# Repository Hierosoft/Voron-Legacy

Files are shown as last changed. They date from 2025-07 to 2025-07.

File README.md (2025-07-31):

# VORON Legacy

Image of Voron Legacy

The official release of the Voron Legacy 3d printer. You can find the BOM and any other relevant information at the [Voron Design]( http://vorondesign.com/voron_legacy) website.

Voron Logo

## Sourcing Guide
- See "VORON 1.6.2" at [sourcing guides](https://vorondesign.com/sourcing_guide?model=VL) page (1.6.2 is same as Legacy according to nemgrea)

## Assembly
- Voron Legacy [Brief assembly Guide](https://forum.vorondesign.com/threads/brief-assembly-guide.176/) by Sanity Agathion, a Voron forum admininstrator.
- Unofficial assembly video series: [Voron Legacy](https://www.youtube.com/playlist?list=PLm2OH_myqt7a_PT0lViufZZBrC22PzAQH) by [Fugatech 3D Printing](https://www.youtube.com/@Fugatech3DPrinting) on YouTube
  - Uses drop-in not slide-in T-nuts, so if using slide-in ones, take care to insert them before locking them out via assembly. See unofficial assembly manual below for image and description of where to insert them.
- [Voron Legacy Unofficial Manual by Poikilos](https://docs.google.com/document/d/1mR3VX70ok1uY0DY2WcfInHhRfALJT7SdbVQVug27Xh0/edit?usp=sharing)
  (WIP)

### Known issues
(Differences mentioned are from actual measurements of motors, making belts centered on gearheads' teeth, etc. Belts are in blend file in Poikilos' Voron Legacy folder on Google Drive, along with these fixes)
- (CAD folder) Make motor shaft of A & B motors 0.152 mm longer so they are 24mm from the screw surface like motors in the 1.6.2 BOM
- Move A (right) gearhead (20T pulley) down by 2.35 so it is 3.45 less than end of motor shaft
- Move B (left) gearhead (20T pulley) up by 0.10217 so it sticks out 1.25mm more than end of motor shaft
- Add (1) M3X40 socket head screw to each side of rear of X Carriage (2 total)
  - Add (2) threaded inserts for them.
  - 1.25mm of the threads are underutilized, so make socket head holes that much deeper.
- Inductive Probe object is unnamed (Fixed in FreeCAD file).

## Contributors
- [deleted user] via Discord
  - "jig for aligning the Y axis rods with the frame" [2022-08-09](https://discord.com/channels/460117602945990666/791364306276450337/1006420060069441627)
    - y_axis_rod_alignment_jig_x4.stl (originally named legacy_tool.stl)
      - (4) are required as cited on [Brief assembly guide](https://forum.vorondesign.com/threads/brief-assembly-guide.176/)
- Ibbanez VL.029 via Discord
  - "X carriage for Stealthburner with CW2 for VL" [2022-08-24](https://discord.com/channels/460117602945990666/791364306276450337/1012131175113949204) as cited on [Brief assembly guide](https://forum.vorondesign.com/threads/brief-assembly-guide.176/)
    - X-VL_left.stl
    - X-VL_right.stl
- Poikilos
  - Alternate leadscrew block for anti-backlash POM nut (2 shank holes, spaced further apart).
    - Fits ["Ender 3 V2 Z axis T8 POM Anti Backlash Spring Loaded Nut Elimination Gap Compatible with Voron 2.4 Ender3 pro 3D Printer 8mm Acme Threaded Rod"](https://www.amazon.com/dp/B088FPNVVF?ref_=ppx_hzsearch_conn_dt_b_fed_asin_title_1) from POLISI3D Store on Amazon.
      - Be aware, these are consumable (will eventually tear apart and lose the threads)! Regular brass ones are recommended in the sourcing guide.
  - Alternate 206mm bed screw spacing parts (for reusing bed from A8 clone such as A3S)
    - 206mm on y: STLs/Tools/alternate_bed_screw_y_spacing_206mm/z_component_alignment_jig-206mm_bed_screw_spacing_A3S.stl
    - 206mm on x: STLs/Z Axis/Bed Carriages/alternate_bed_screw_x_spacing_206mm/
  - Blend file with the above, blind joints, and taller to use prefabricated Voron 2.4 frame:
    [Poikilos' Voron Legacy Folder](https://drive.google.com/drive/folders/1cWyBRrxuDkORSMTYZdLJZKc8Kg_imgok?usp=sharing) on Google Drive (too large for git except with LFS).
    - [Generated BOM](https://drive.google.com/file/d/1eSlRInvPNuWncBucrcRtuzRmA0uxTkT_/view?usp=sharing), reusing a prefabricated Voron 2.4 frame size
      - No 320 motors exist though, so use a regular stepper motor, flexible coupling (See unofficial sourcing guide below), and ~300mm lead screws such from A8 clone such as A3S.
    - Unofficial sourcing guide by Poikilos: [https://docs.google.com/spreadsheets/d/1isZgUZrGUJIj4jxUcvnwxng9hJ9_i8DxyWfmX4hRLIU/edit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](Building VORON Legacy but with V2.4 Frame and salvaged A8 clone)
      - based on "VORON 1.6.2" at [sourcing guides](https://vorondesign.com/sourcing_guide?model=VL) (1.6.2 is same as Legacy according to nemgrea)

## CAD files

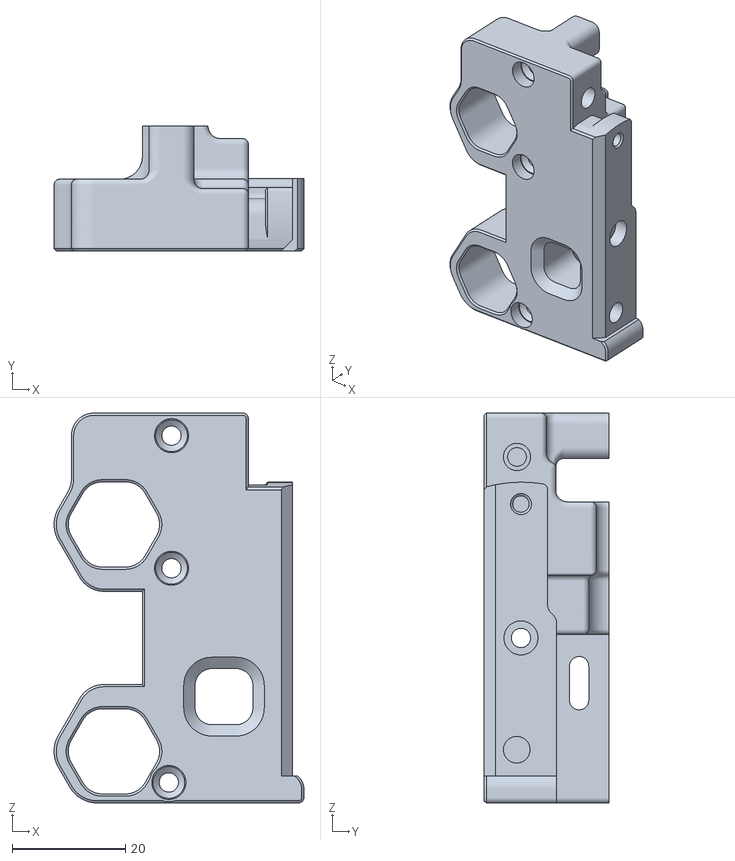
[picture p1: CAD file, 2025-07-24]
STLs/Gantry/X Carriage/Printheads/Stealthburner with CW2/X-VL_left.stl
44.1 x 22.0 x 68.8

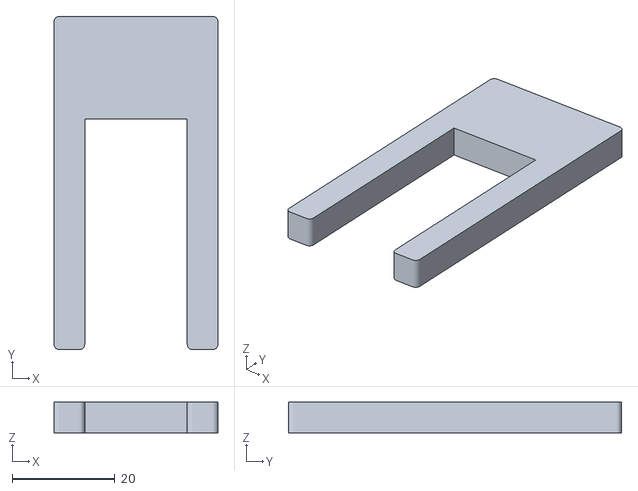
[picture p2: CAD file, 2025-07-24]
STLs/Tools/y_axis_rod_alignment_jig_x4.stl
32.0 x 65.0 x 6.00

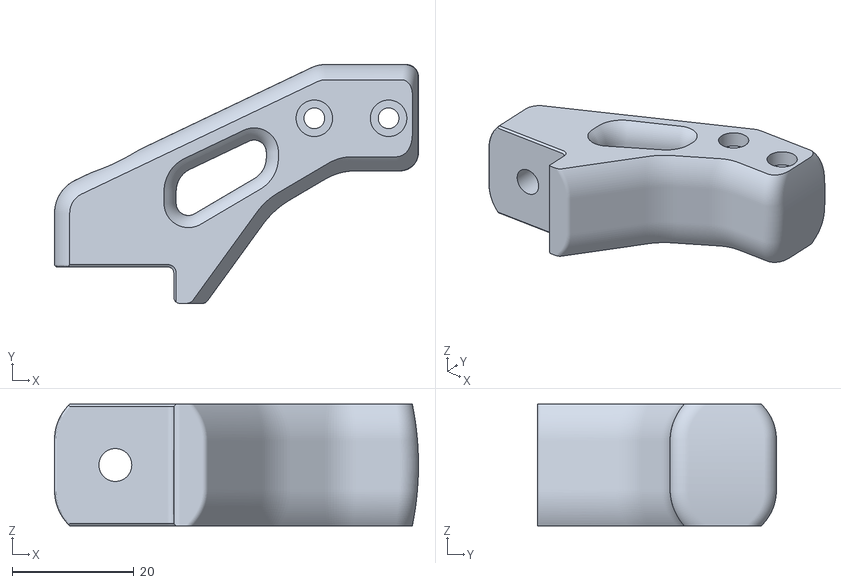
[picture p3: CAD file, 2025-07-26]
STLs/Z Axis/z_shaft_support_lower_a_x2.stl
59.8 x 39.3 x 20.0

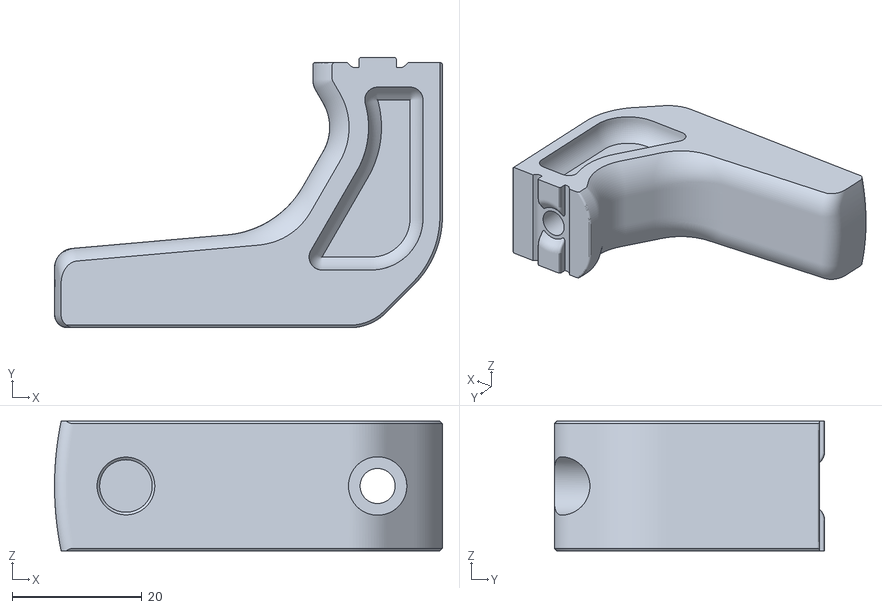
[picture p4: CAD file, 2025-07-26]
STLs/Z Axis/z_shaft_support_upper_x4.stl
59.8 x 41.7 x 20.0

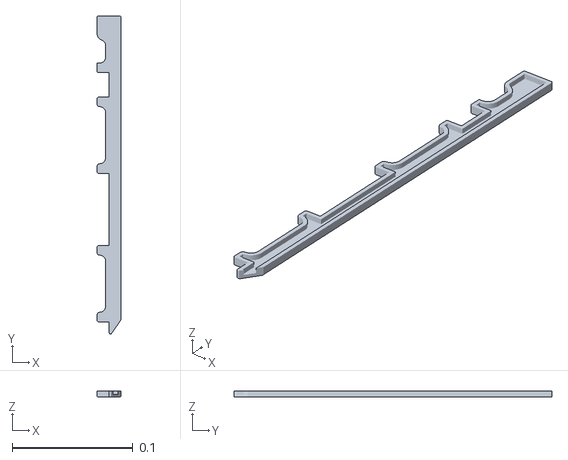
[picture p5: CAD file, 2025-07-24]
STLs/Tools/alternate_bed_screw_y_spacing_206mm/z_component_alignment_jig-206mm_bed_screw_spacing_A3S.stl
0.0196 x 0.263 x 0.005

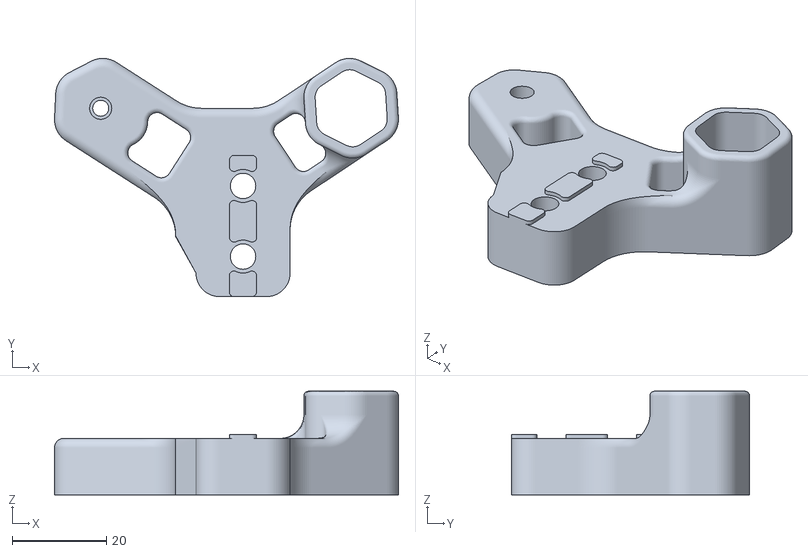
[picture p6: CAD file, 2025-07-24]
STLs/Z Axis/Bed Carriages/alternate_bed_screw_x_spacing_206mm/bed_carriage_upper_b_x2-206mm_bed_screw_y_spacing.stl
73.1 x 50.6 x 22.0

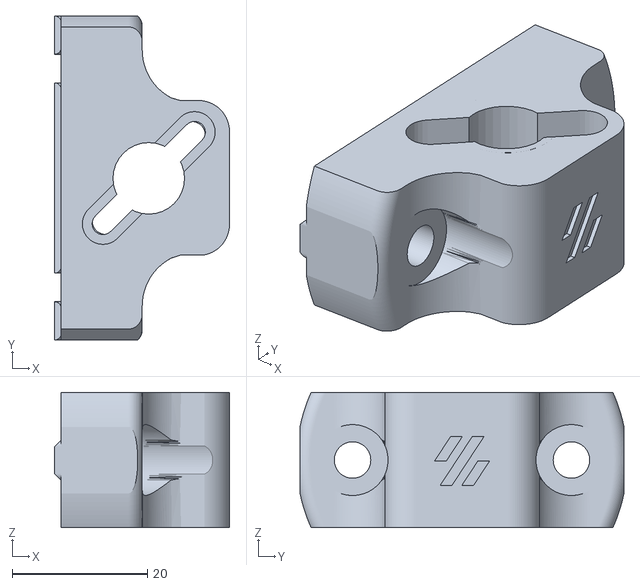
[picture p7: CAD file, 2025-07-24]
STLs/Z Axis/Bed Carriages/for-2-screw-POM_nut/z_leadscrew_block_x2mirror+.5mmx2_clearance-for-2screw-POM-nut.stl
25.9 x 48.0 x 20.0

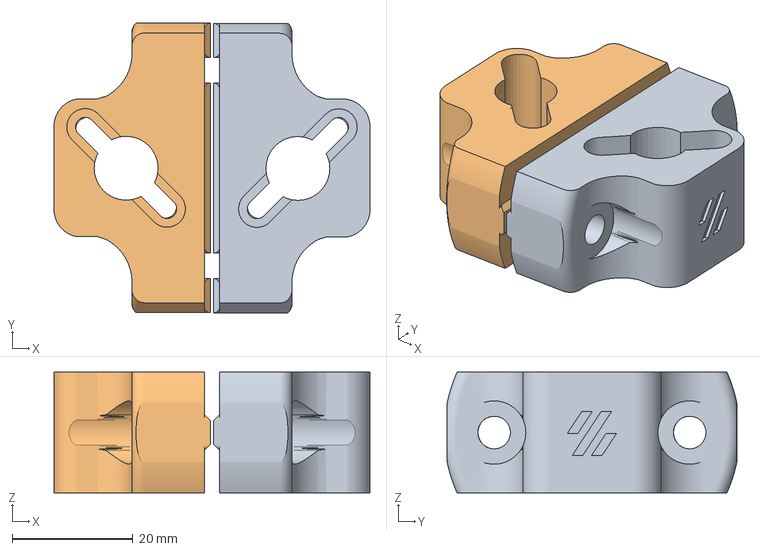
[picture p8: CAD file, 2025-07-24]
STLs/Z Axis/Bed Carriages/for-2-screw-POM_nut/z_leadscrew_block+.5mmx2_clearance-for-2screw-POM-nut-x2-mirrorred.3mf
52.4 x 48.0 x 20.0 mm
z_leadscrew_block_x2+.5mmx2_clearance.stl x 2

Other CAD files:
STLs/Gantry/X Carriage/Printheads/Stealthburner with CW2/X-VL-right.stl
STLs/Z Axis/z_shaft_support_lower_b_x2.stl
STLs/Z Axis/Bed Carriages/alternate_bed_screw_x_spacing_206mm/bed_carriage_upper_a_x2-206mm_bed_screw_y_spacing.stl

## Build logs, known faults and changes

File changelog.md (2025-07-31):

# Changelog

All notable changes to this project will be documented in this file.

The format is based on [Keep a Changelog](https://keepachangelog.com/en/1.1.0/).

## 2025-07-27
### Fixed
- Named unnamed inductive_probe.

## 2025-07-27
(only to blend file in Poikilos' Voron Legacy Folder on Google Drive)
### Added
- Belts (blend file)
### Fixed
- Edit end of A & B motor shafts so they are 24mm from the screw surface like motors in the 1.6.2 BOM.
- Move A (right) gearhead (T20 pulley) down by 2.35 (blend file) so it is out 3.45 less than end of motor shaft
- Move B (left) gearhead (T20 pulley) up by 0.10217 (blend file) so it sticks out 1.25mm more than end of motor shaft
- Move entire scene by -76.8922,-135.07,360.175 mm so top surfaces of bottom bars is at 0 on z axis and outer edge is at 0,0 on x-y plane.
  - Then rotate 180 on world origin so that x and y move in the same direction as they would in firmware and slicer software.

## 2025-07-26
(Poikilos)
### Fixed
- Named more parts in FreeCAD file (and Poikilos' blend file in Google Drive link):
  `front_idler_*`, `bed_carriage_*`, `z_leadscrew_block_x2` `z_shaft_support_upper_*`, `*_drive_unit_*`, `z_shaft_support_lower_*_x2`, `z_motor_mount_*_x2*`, `bowden_adapter_*`, `[a]_bowden_cable_cover`, `blower_housing_rear`, `[a]_blower_housing_front`, `printhead_*_e3dv6`, `probe_retainer_bracket`, `[a]_belt_clip_x2`, `enclosure_cover`, `psu_stabilizer` (was misspelled "Stabalizer"), `xy_joint_*`, `y_bearing_retainer_front_x2`,
  - Helps find the STL you need. Example: identifying parts in (unofficial) documentation visually rather than using a file search.
- Suffix assemblies for parts above with **"_ASSEMBLED"** to avoid confusion on export where parts are fused into one mesh but must be printed separately (impossible to print if fused, but at least user is clued into that fact and knows to not export that. This is fixed in Poikilos' blend file.).
- Parts with ".R" or rear/front in name do not have to be exported more than once (filename is part before dot).

## 2025-07-26
(Poikilos)
### Fixed
- Rename misspelled files: (3) Z axis `*support*` files formerly `*suport*`.

## 2025-07-24
(Poikilos)
### Added
- y axis rod alignment tool [by deleted user on Discord]
- "X carriage for Stealthburner with CW2 for VL" by Ibbanez VL.029 on Discord.

## 2025-07-05
(Poikilos)
### Added
- Added Google Drive link to Blend file (since blend file is over 100MB, so it cannot be uploaded to GitHub except with LFS).
  - Converted .step file to .gltf using [CAD Assistant](https://www.opencascade.com/products/cad-assistant/) (Generates good normals so less geometry is required, according to mrpraline on blender.stackexchange.com [Oct 18, 2020](https://blender.stackexchange.com/a/199076/12998)
  - Converted .gltf file to .blend file using Blender 3.6.19.
    - The intermediate models were large (nearly as large as the blend file), so not committed.
- bed carriage for 206mm screw spacing (for reusing bed from A8 clone such as JGAURORA A3S)
  - stock screw spacing (x, y): 214.6, 150
  - reused A8 clone bed screw spacing: 206, 206
  - difference: 8.6, -56
  - Changed Y bed screw spacing from 150 to 206 (each outward toward front & back by 28 mm). Affects:
    - position of vertical rod mounts (See alternate z axis component alignment jig)
    - bed carriage uppers (use longer bar so mounts can be spaced more)
      - requires (2) 186mm 2020 extrusions rather than the stock 130.
  - Changed X bed screw spacing from 214.6 to 206 (each inward by 4.3 mm)
    - Moved hole & added more material (See alternate bed carriage uppers)
  - Changed PCB heater size to 213.5 x 213.5 (reduced by 7.55 mm on each side).
    - This is just to help mods/changes account for heating elements.

### Changed
(Poikilos)
- Make blind joint version blend file
  - Scaled to match a prefabricated VORON V2.4 frame kit.
  - Increased length of vertical HFSB5-20 from 370 to 430
    - increase by 60
    - move down by 20
  - Increase length of vertical linear rods by 340 (320 + 20)
  - Rotate z 90 so X and Y of printer line up with world
  - Move frame to center it on the world origin.

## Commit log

2025-07-24 Link to unofficial assembly guides.
2025-07-24 Add missing Y-axis rod alignment jig.
    [y_axis_rod_alignment_jig_x4.stl]
2025-07-24 Add "X carriage for Stealthburner with CW2 for VL" by Ibbanez VL.029
    [X-VL-right.stl, X-VL_left.stl]
2025-07-24 Add alternate leadscrew block for anti-backlash POM nut. Add alternate 206mm bed screw spacing parts (jig for Y, bed carriage uppers for x). Link to blend file with blind joints and using prefabricat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
    [bed_carriage_upper_a_x2-206mm.stl, bed_carriage_upper_b_x2-206mm.stl, z_component_alignment_jig-206mm_bed_screw_spacing_A3S.stl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]
2025-07-24 Add purchase link for leadscrew nut.
2025-07-25 Rename alternate bed carriage uppers for clarity.
    [bed_carriage_upper_a_x2-206mm_bed_screw_y_spacing.stl, bed_carriage_upper_b_x2-206mm_bed_screw_y_spacing.stl]
2025-07-26 Rename misspelled files.
    [z_shaft_support_lower_a_x2.stl, z_shaft_support_lower_b_x2.stl, z_shaft_support_upper_x4.stl]
2025-07-26 Name the unnamed assemblies and solids in FreeCAD file (See Changelog).
2025-07-28 Fix recently added gearhead terminology.
2025-07-29 Note issues with socket head hole depth.
